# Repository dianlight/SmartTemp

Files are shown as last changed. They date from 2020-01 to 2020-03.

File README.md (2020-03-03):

<!--
*** Thanks for checking out this README Template. If you have a suggestion that would
*** make this better, please fork the repo and create a pull request or simply open
*** an issue with the tag "enhancement".
*** Thanks again! Now go create something AMAZING! :D
***
***
***
*** To avoid retyping too much info. Do a search and replace for the following:
*** github_username, repo, twitter_handle, email
-->

<!-- PROJECT SHIELDS -->
<!--
*** I'm using markdown "reference style" links for readability.
*** Reference links are enclosed in brackets [ ] instead of parentheses ( ).
*** See the bottom of this document for the declaration of the reference variables
*** for contributors-url, forks-url, etc. This is an optional, concise syntax you may use.
*** https://www.markdownguide.org/basic-syntax/#reference-style-links
-->
[][contributors-url]
[][forks-url]
[][stars-url]
[][issues-url]
[][license-url]
[][linkedin-url]

<!-- PROJECT LOGO -->
<br />
<p align="center">
  <a href="https://github.com/dianlight/SmartTemp">
    <!--
    <img src="images/logo.png" alt="Logo" width="80" height="80">
    -->
  </a>

  <h3 align="center">Smart Temp</h3>

  <p align="center">
    An DIY Smart Thermostat
    <br />
    <!--
    <a href="https://github.com/dianlight/SmartTemp"><strong>Explore the docs »</strong></a>
    <br />
    <br />
    -->
    <a href="https://github.com/dianlight/SmartTemp/blob/master/CHANGELOG.md">Changelog</a>
    ·
    <a href="https://github.com/dianlight/SmartTemp/issues">SmartTemp Bug</a>
    ·
    <a href="https://github.com/dianlight/SmartTemp/issues">Request Feature</a>
  </p>
</p>

<!-- Donations -->

<a href="https://www.buymeacoffee.com/ypKZ2I0" target="_blank">Buy Me A Coffee</a>

<!-- TABLE OF CONTENTS -->
## Table of Contents

- [Table of Contents](#table-of-contents)
- [About The Project](#about-the-project)
  - [Built With](#built-with)
- [Getting Started](#getting-started)
  - [Hardware Prerequisites](#hardware-prerequisites)
  - [Circuit](#circuit)
  - [Environment Prerequisites](#environment-prerequisites)
  - [Installation](#installation)
- [Config.h options](#configh-options)
- [Features / Whishlist](#features--whishlist)
- [Roadmap](#roadmap)
- [User Manual](#user-manual)
  - [Encoder function](#encoder-function)
  - [Thermal confort mode (Advanced)](#thermal-confort-mode-advanced)
  - [PMV/PPD method](#pmvppd-method)
  - [Modes](#modes)
  - [In house / away selection](#in-house--away-selection)
- [Contributing](#contributing)
- [License](#license)
- [Contact](#contact)
- [Acknowledgements](#acknowledgements)

<!-- ABOUT THE PROJECT -->
## About The Project

<!-- [![Product Name Screen Shot][product-screenshot]](https://example.com) -->
Just another smart thermostat!

In a smart home, a smart thermostat cannot be missing. So why not build one at low cost and with all the features that interest me.

The project started using material left over from other projects and respecting the following requirements:

* Low cost
* Independence from Cloud services (privacy first!)
* Small size (must be contained in a US size box)
* Be smart but if necessary work without WiFi and / or external controller
* KISS. Being able to be used by my wife, daughter, son, mother, father, grandmother, grandfather -> the whole family!

### Built With

* [Platform IO](http://platformio.org)

<!-- GETTING STARTED -->
## Getting Started

To get a local copy up and running follow these simple steps.

### Hardware Prerequisites

For a detailed list of components refer to the documentation (BOM)

1. I2C Advance Extender based on ATMEGA8A-PU (See project [at8i2cgateway](https://github.com/dianlight/a8i2cGateway))
2. MCU ESP-01 or ESP-01S
3. Serial programmer
4. I2C Oled display
5. Rotary encoder
6. DHT22 sensor
7. Relay 
8. 5v power source ( I used an Hi-Link 220v to 5v but you can use alse batteries )
9. Wires and Connectors 

### Circuit

***!Work in progress!***

### Environment Prerequisites

1. Platform IO ( to compile and generate the firmware )
2. An HomeAssistant installation ( used as Smart Controller ) ___(Optional)___ 
3. An MQTT Borker ___(Optional)___
4. An WiFi capable device like SmartPhone.
5. An WiFi internet connection

### Installation
 
1. Burn the bootloader into the ATMEGA8 with Arduino IDE and the SPI/ASP programmer
2. Clone the SmartTemp
```sh
git clone https://github.com/dianlight/SmartTemp.git
```
3. Open the project with Platform IO
4. Configure the firmware 
```src/include/Config.h```
5. Build and flash your firmware

<!-- USAGE EXAMPLES -->
## Config.h options

***!Work in progress!***

<!-- FEATURES -->
## Features / Whishlist

- [x] Standalone Thermostat
  - [x] Current Room Temperature
  - [x] Current Room Humidity
  - [x] 3 levels of temperatures. (ECO, NORMAL and CONFORT)
  - [x] Week programming (15min resolution)
- [ ] Supported units
  - [x] Celsius mode
  - [ ] Fahrenheit mode ( [Wikipedia](https://en.wikipedia.org/wiki/Fahrenheit) )
- [x] Advanced Thermostat
  - [x] Away/In_house temp control
  - [x] Auto, Manual and Off mode
  - [ ] Thermal confort mode 
    - [ ] [PMV/PPD method](https://en.wikipedia.org/wiki/Thermal_comfort#PMV/PPD_method)
    - [ ] [Adaptive comfort model](https://en.wikipedia.org/wiki/Thermal_comfort#Adaptive_comfort_model)<sup>1</sup>
    - [ ] [ASHRAE-55](https://comfort.cbe.berkeley.edu/)<sup>2</sup>
    - [ ] [EN-16798](https://comfort.cbe.berkeley.edu/)<sup>2</sup>
- [x] Smart Thermostat (Wifi remote controlled)
  - [x] MQTT transport
  - [x] HomeAssistant climate compatibility (via MQTT integration)
    - [ ] Homeassistant room presence integration ( auto AWAY/NORMAL mode )
  - [x] NTP clock sync (daylight auto switch)
    - [ ] Time Zone configuration
- [x] WebInterface
  - [ ] Mobile WebApp
- [ ] External sensor
  - [ ] Wifi temperature sensor
  - [ ] Wifi pressure sensor
  - [ ] Wifi air speed sensor
  - [ ] Home Assistant collector
- [x] Enclosure (3D STL printable models)
  - [x] Italian BTicino Living 2Gang
  - [ ] EU standard
  - [ ] UK standard
  - [ ] US standard

_*Checked are implemented_

_<sup>1</sup>Require external temperature sensor_

_<sup>2</sup>Require external temperature, pressure sensor and internet connection_

<!-- ROADMAP -->
## Roadmap

See the [open issues](https://github.com/dianlight/SmartTemp/issues) for a list of proposed features (and known issues).

<!-- USER MANUAL -->
## User Manual

### Encoder function

***!Work in progress!***

### Thermal confort mode (Advanced)

***!Work in progress not yet implemented!*** 

The thermal confort mode allows you to set the thermostat not based on the real  desired temperature but on the basis of the [confort temperature](https://en.wikipedia.org/wiki/Thermal_comfort#Interplay_of_temperature_and_humidity). This significantly increases comfort by reducing consumption.

### [PMV/PPD method](https://en.wikipedia.org/wiki/Thermal_comfort#PMV/)

![Temp/Humidity](https://upload.wikimedia.org/wikipedia/commons/thumb/a/a0/Temperature-relative_humidity_chart_-_PMV_method.png/1024px-Temperature-relative_humidity_chart_-_PMV_metho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)

### Modes 

| Mode | Description | Home modfity | Away modify | Note |
| --- | --- | --- | --- | --- |
| Auto | Follow the Week program to set *Eco*, *Normal* or *Confort* target temp | none | &plusmn; delta | |
| Manual | Follow the setting of selected target temp | none | &plusmn; delta | return to *Auto* mode after impoisted time |

### In house / away selection

| Selection | Mode | Description | Function | Note |
| --- | --- | --- | --- | --- |
| In house  | Auto | Standard mode | Follow week program | |
| In house  | Manual | Temporary mode | Follow selected target temperature until timeout expire | Automatic return to *Auto* mode |
| Away      | Auto | Advanced mode | Follow week program with a &plusmn; temperature delta | |
| Away      | Eco  | Advanced mode | Lock to *Eco* target temperature  with a &plusmn;  delta | No automatic return to *Auto* mode |
| Away      | Normal  | Advanced mode | Lock to *Normal* target temperature with a &plusmn;  delta | No automatic return to *Auto* mode |
| Away      | Confort  | Advanced mode | Lock to *Confort* target temperature with a &plusmn;  delta | No automatic return to *Auto* mode |

<!-- CONTRIBUTING -->
## Contributing

Contributions are what make the open source community such an amazing place to be learn, inspire, and create. Any contributions you make are **greatly appreciated**.

1. Fork the Project
2. Create your Feature Branch (`git checkout -b feature/AmazingFeature`)
3. Commit your Changes (`git commit -m 'Add some AmazingFeature'`)
4. Push to the Branch (`git push origin feature/AmazingFeature`)
5. Open a Pull Request

<!-- LICENSE -->
## License

Distributed under the GPL3 License. See `LICENSE` for more information.

<!-- CONTACT -->
## Contact

<!--
Your Name - [@twitter_handle](https://twitter.com/twitter_handle) - email
-->

Project Link: [https://github.com/dianlight/SmartTemp](https://github.com/dianlight/SmartTemp)

<!-- ACKNOWLEDGEMENTS -->
## Acknowledgements

Icons made by <a href="https://www.flaticon.com/authors/pixel-perfect" title="Pixel perfect">Pixel perfect</a> from <a href="https://www.flaticon.com/" title="Flaticon"> www.flaticon.com</a>

<!--
* [RobTillaart](https://github.com/RobTillaart/) for the Arduino libraries
* [soligen2010](https://github.com/soligen2010/) for the ClickEncoder fork
  -->

<!-- MARKDOWN LINKS & IMAGES -->
<!-- https://www.markdownguide.org/basic-syntax/#reference-style-links -->
[contributors-shield]: https://img.shields.io/github/contributors/dianlight/SmartTemp.svg?style=flat-square
[contributors-url]: https://github.com/dianlight/SmartTemp/graphs/contributors
[forks-shield]: https://img.shields.io/github/forks/dianlight/SmartTemp.svg?style=flat-square
[forks-url]: https://github.com/dianlight/SmartTemp/network/members
[stars-shield]: https://img.shields.io/github/stars/dianlight/SmartTemp.svg?style=flat-square
[stars-url]: https://github.com/dianlight/SmartTemp/stargazers
[issues-shield]: https://img.shields.io/github/issues/dianlight/SmartTemp.svg?style=flat-square
[issues-url]: https://github.com/dianlight/SmartTemp/issues
[license-shield]: https://img.shields.io/github/license/dianlight/SmartTemp.svg?style=flat-square
[license-url]: https://github.com/dianlight/SmartTemp/blob/master/LICENSE
[linkedin-shield]: https://img.shields.io/badge/-LinkedIn-black.svg?style=flat-square&logo=linkedin&colorB=555
[linkedin-url]: https://www.linkedin.com/in/lucio-tarantino-8ab9a3/
[product-screenshot]: images/screenshot.png
[buy-me-a-coffe]: https://www.buymeacoffee.com/ypKZ2I0

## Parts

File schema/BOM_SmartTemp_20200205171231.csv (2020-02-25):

ID | Name | Designator | Footprint | Quantity | Manufacturer Part | Manufacturer | Supplier | Supplier Part | LCSC Assembly
1 | 10K | R1 | R10K | 1
2 | 3PIN | J1 | 3PIN | 1
3 | 16MHz | X1 | HC-49US_L11.5-W4.5-P4.88 | 1 | XIHCELNANF-8MHZ | TAITIEN Elec | LCSC | C295088
4 | AC220VPIN | U10 | AC220PIN | 1 | AC220VPIN
5 | ESP Program | U3 | 2 PIN | 1 | Precision potentiometer100Ω
6 | ESP Serial | U8 | 2 PIN | 1 | Precision potentiometer100Ω
7 | A8 Serial | U9 | 2 PIN | 1 | Precision potentiometer100Ω
8 | 330 | R6,R7 | PKG-0.25W RESISTOR | 2 | MCF 0.25W 120R | MULTICOMP | Element14 | 9339116
9 | ROTARY_ENCODER_LABELED | U7 | 5 PIN | 1 | ROTARY_ENCODER | STMicroelectronics |  | C157406 | Yes
10 | DHT22 | U4 | 4PIN | 1
11 | A8 Reset/Program | SW1 | SW-TH_4PIN-L6.00-W6.00 | 1 | Switch,6*6*6Plastic head,260G, 0.25mm,Straight line | BBJ | LCSC | C71836
12 | ESP Reset | SW2 | SW-TH_4PIN-L6.00-W6.00 | 1 | Switch,6*6*6Plastic head,260G, 0.25mm,Straight line | BBJ | LCSC | C71836
13 | 3K3 | R2,R5 | AXIAL10 | 2 | Resistor MF25 3K3, 0.25W |  | Element14 | 934-1749
14 | 22pF | C1,C2 | CERAMIC-2.54 | 2 | CS1-D5Y5V2A104ZSP |  | SeeedStudio | 302010200
15 | HILINK | U1 | HI-LINKAC-5VDC | 1
16 | SSH1106_1.3in_128x64_I2C_OLED_NEW | DISP1 | I2C CONNECTOR | 1 | Tribium
17 | ATMEGA8A-PU | U2 | DIP-28_L34.6-W7.3-P2.54-LS10.2-BL | 1 | ATMEGA8A-PU | MICROCHIP | LCSC | C34931
18 | ARDUINO KY-019W 5V | U6 | ARDUINO RELAY KY-019 5V | 1 | SRD-05VDC-SL-C |  | eBay | undefined
19 | AMS117，SOT223 COPY | U5 | 3 PIN | 1
20 | 0.1uF | CC1,CC2 | CAP_CER | 2
21 | ESP-01S_C82893 | MK1 | WIRELM-TH_ESP-01S | 1 | ESP-01S | Ai-Thinker | LCSC | C82893

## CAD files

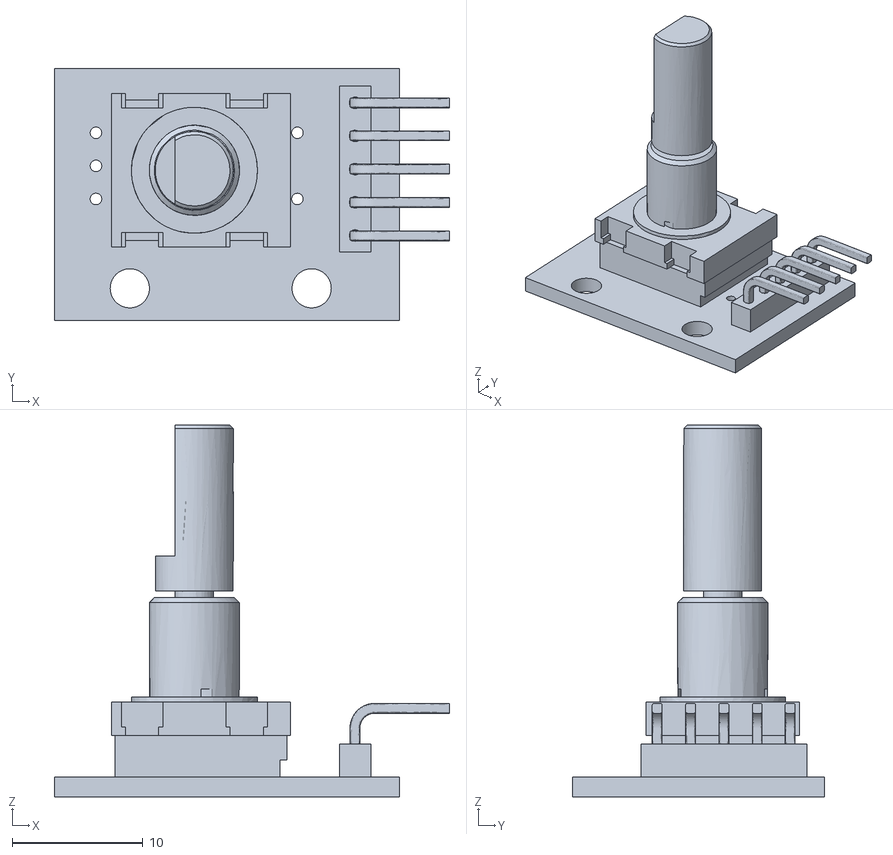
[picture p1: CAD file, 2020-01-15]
case/Rotary_Encorder_KY-040.stl
30.2 x 19.3 x 28.5

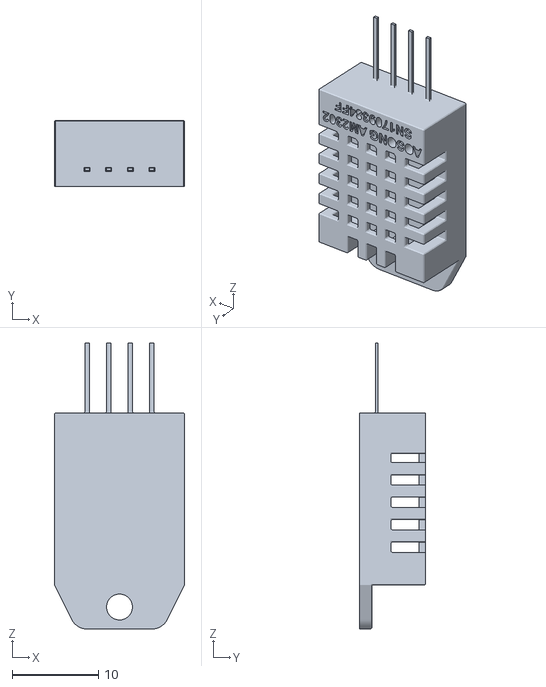
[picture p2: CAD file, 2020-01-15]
case/DHT22.stl
15.1 x 7.70 x 33.2

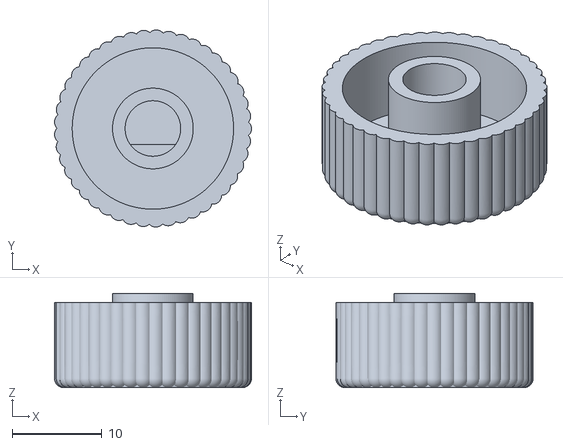
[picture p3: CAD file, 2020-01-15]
case/Rotary_Encoder_Knob.stl
22.0 x 22.0 x 10.5

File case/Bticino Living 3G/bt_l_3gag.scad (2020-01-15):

//use<threads.scad>
//use <096Oled.scad>;
include <NopSCADlib/lib.scad>
use <threadlib/threadlib.scad>
use <OLED_13_128_64.scad>

include <096OledDim.scad>;


renderNop = false;
nutmount = true;

$fn=60;

union(){

    difference(){
        translate([0,0,-0.8])extBox([43.3,66.0,58.8]);
        translate([0.1,0,1])extBox([41.0,63,58.8]);
        translate([39.5,0,19]) cube([4,66.0,48.8]);
        translate([39.5,0,19]) rounded_rectangle([4,66.0,48.8],r=1,center=false);
        translate([1.2,2.0,18.8]) cube([43.0,62.0,40]);
        translate([20,67,33]) rotate([90,90,0]) tearslot(68.2, 10,20, center = false, truncate = true);
  
        
        // OLED
        rotate([0,180,0]){
            translate([-23.5,19.9,-4]) {
              rounded_rectangle([18.8,31.8,5],r=1,center=false);
            }
        }
 //       rotate([180,0,90])
 //         translate([20,25,-2]) {
 //           OLED_13_128_64_I2C(1,0);  
 //           DisplayLocalize(type=I2CSPI7, align=2, dalign=1)
 //               translate([0,0,6.0/2])
 //                   cube([CRIUS_LVW,CRIUS_LVL,6.0], center=true);
 //         }
        // Enc
        rotate([180,0,180])  
          translate([-28.05, 55,-2])
            cylinder(h=5,r=3.8);
          
          
/*        
       translate([22,10,0.5])
          rotate([0,0,-90])
          scale([0.1, 0.1, 0.1])
         surface(file = "lamp.png", center = true, invert = true);
        
       translate([22,32,0.5])
          rotate([0,0,-90])
          scale([0.1, 0.1, 0.1])
         surface(file = "lamp2.png", center = true, invert = true);

       translate([22,55,0.5])
          rotate([0,0,-90])
          scale([0.1, 0.1, 0.1])
         surface(file = "lamp2.png", center = true, invert = true);
 */  
       
        
        // Buco bottone Reset
        translate([2,18,-2])cylinder(r=1,h=28,$fn=60);
        translate([2,11,-2])cylinder(r=1,h=28,$fn=60);
        //translate([39,17,0]) linear_extrude(height=2)  rotate([180,0,90]) text("Connesso", font = "Liberation Sans",  size = 1.3);
        // Buco DHT22
        translate([12,50.9,-2]) rounded_rectangle([16,21,5],r=0.5,center=false);
        translate([6,61+2,1.7]) cube([12,5,2]);
        // Buco fissaggio OLED
        translate([4,-2,2]) cube([35,5,2]);
        

 
    }
//        translate([3.5,40.5,-2]) cube([16,22,5]);

     rotate([0,180,0])
      translate([-40,3,-3])  {
        translate([33,32,0]) m2hold();  
        translate([33,32-30,0]) m2hold();  
        translate([32-27,32-30,0]) m2hold();  
        translate([32-27,32,0]) m2hold();  
//        translate([32-27,32,0]) nut("M2",turns=5,Douter=4.2);  
      }

    if(nutmount){
         translate([33.2,46,0.5]){
            nut("M2",turns=26,Douter=6); 
            translate([-7,0,4.7]) cube([12,4,12],center=true);
            translate([5.5,0,4.7]) cube([9,4,12],center=true);
         }
     }
      
    if(renderNop){
        rotate([0,180,0])
          translate([-39,3,-4]) {
 //           DisplayModule(type=I2CSPI7, align=2, G_COLORS=true); 
            OLED_13_128_64_I2C(1,0);  
   
          }
        rotate([180,0,180])  
          translate([-163,207,-14])
            import("../Rotary_Encorder_KY-040.stl");   
          
        translate([19,61,3.5]) rotate([90,180,0]) import("../DHT22.stl");
         
        translate([27,55,-15]) import("../Rotary_Encoder_knob.stl"); 
    }
    
    PERF60x40_1 = ["PERF60x40", "Perfboard 60 x 40mm"
       , 60
       , 40
       , 1.6
       , 0
       , 2.3
       , 0
       , "green"
       , true
       , 
       [ 
         [1.9,1.9],
         [-1.9,1.9],
         [1.9,-1.9],
         [-1.9,-1.9]
       ], [], [], [5.87, 3.49]];
       
      rotate([90,0,90]) translate([33,37,10]){
          if(renderNop)pcb(PERF60x40_1);
          pcb_screw_positions(PERF60x40_1){
            translate([0,0,-9.5]){
               if(nutmount) nut("M2",turns=20,Douter=6); 
            } 
          }
      }

    
    
    
    // Supporti Scheda
 //   translate([3+1.9,   7,2]) threadSupport();
 //   translate([3+1.9,   53+7,2]) threadSupport();
 //   translate([38+0.6,  53+7,2]) threadSupport();
 //   translate([38+0.6,  7,2]) threadSupport();
 //   %translate([2,3,10]) cube([40,60.2,1.5]);
 
    // Ganci Living
   translate([0,16.9,18.8-8.6])  rotate([90,0,270]) hookMount();

   translate([43.3,16.9-11.5,18.8-8.6])  rotate([90,0,-270]) hookMount();

   translate([0,16.9+21.7,18.8-8.6])  rotate([90,0,270]) hookMount();

   translate([43.3,16.9-11.5+21.7,18.8-8.6])  rotate([90,0,-270]) hookMount();

   translate([0,16.9+(21.7*2),18.8-8.6])  rotate([90,0,270]) hookMount();

   translate([43.3,16.9-11.5+(21.7*2),18.8-8.6])  rotate([90,0,-270]) hookMount();
    
    
}

module extBox(dim){
    translate([21.6,33,29.4]) rotate([90,90,0]) rounded_rectangle([dim.z,dim.x,dim.y],r=4,center=true);
//    intersection(){
//      cube(dim);
//       translate([43.5/2,66,58]) 
//            rotate([90,0,0]) 
//                cylinder(r1=60,r2=60,h=66,$fn=260);
//
//    }

}

module threadSupport(){
    difference () {
        cylinder (r=3, h=5, $fn=100);
     metric_thread (diameter=2, pitch=1, length=6, internal=true, n_starts=6);
    }
}


module hookMount(){
    union(){
        difference(){
            cube([11.8,8.6,3-1.2]);
            translate([(11.8-9.2)/2,1.9,0]) cube([9.2,8.4,3-1.2]);
            translate([3.3,0,0]) cube([4.9,8.6,3-1.2]);
        }
        CubePoints = [
          [  3.3,  5.4,  0 ],  // 0
          [  3.3+4.9,  5.4,  0 ],  // 1
          [  3.3+4.8,  8.6,  0 ],  // 2
          [  3.3, 8.5, 0 ], // 3
          [  3.3,  5.4,  3-1.2 ],  //4
          [  3.3+4.9,  5.4,  3-1.2 ], //5 
          [  3.3+4.9,  10.1,  3-1.2 ],  //6
          [  3.3,  10.1,  3-1.2 ],  //7
         ]; 
  
        CubeFaces = [
          [0,1,2,3],  // bottom
          [4,5,1,0],  // front
          [7,6,5,4],  // top
          [5,6,2,1],  // right
          [6,7,3,2],  // back
          [7,4,0,3]]; // left
          
        polyhedron( CubePoints, CubeFaces );
    }
    
    
}

module m2hold() {
    translate([0,0,-2.2]){
      difference(){ 
        union(){   
           cylinder(r1=1.5,r2=3.9/2,h=2);
           cylinder(r=1.5,h=6);
        }
        cube([4,0.8,7],center=true);
 //       cube([0.8,4,7],center=true);
      }
    }
}

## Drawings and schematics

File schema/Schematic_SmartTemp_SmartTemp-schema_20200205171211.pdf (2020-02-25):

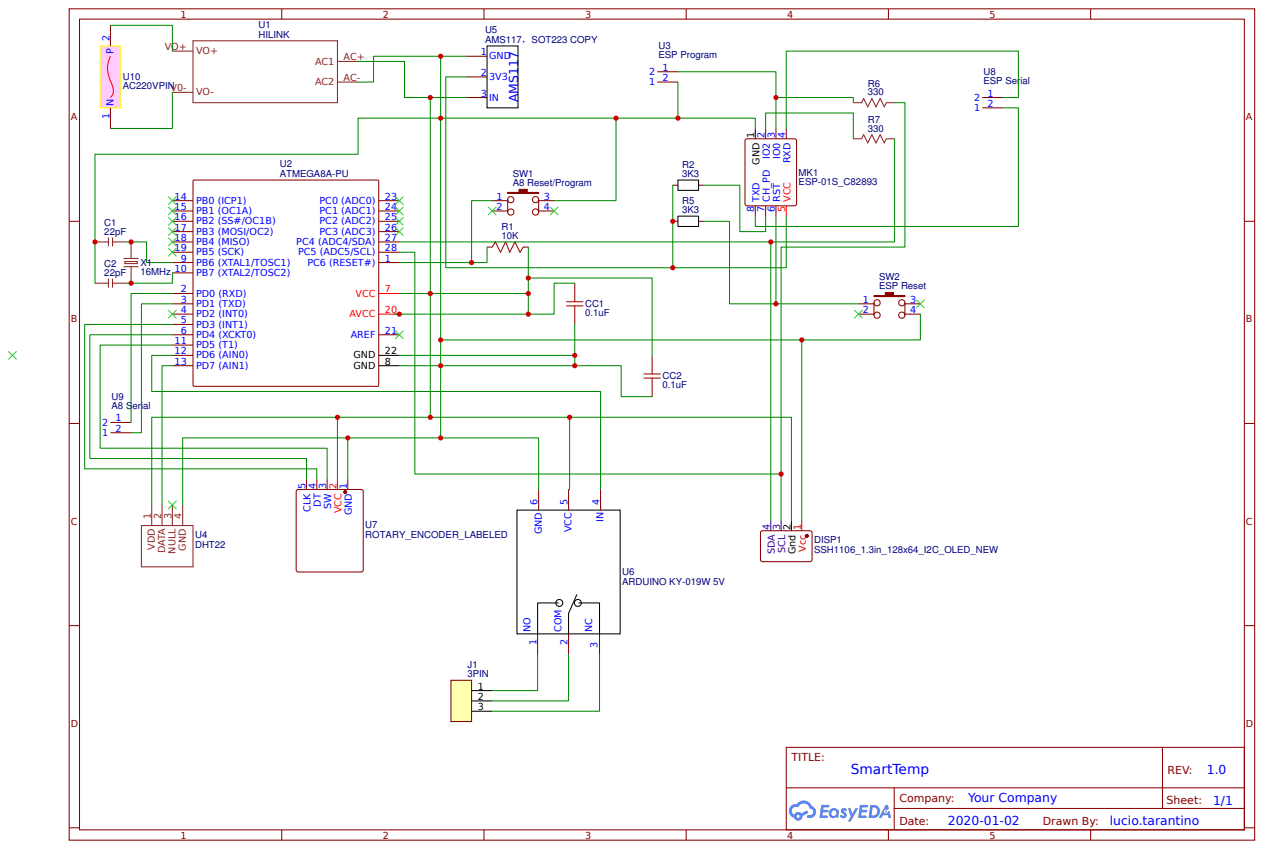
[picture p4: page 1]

RXD 4 VCC 5 RST 6 CH_PD 7 TXD 8

Vcc 1 Gnd 2 SCL 3 SDA 4

Drawn By: lucio.tarantino

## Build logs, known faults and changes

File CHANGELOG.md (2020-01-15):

# **Change Log** 📜📝

All notable changes to the "**SmartTemp**" WhatItIs/program/extension/API/whatever will be documented in this file.

The format is based on [Keep a Changelog](https://keepachangelog.com/en/1.0.0/) and this project adheres to [Semantic Versioning](https://semver.org/spec/v2.0.0.html).

---

# Changelog

## [Unreleased]

### Added

- Initial version.

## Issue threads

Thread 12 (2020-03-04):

Web UI responsive on small device.

dianlight, 2020-03-04:
Correct web ui on small device ( phones )

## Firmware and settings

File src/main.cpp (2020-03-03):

/*
 * SmartTemp
 * 
 * Smart Thermostat
 */
#include "EvoDebug.h"
#include <ESP8266mDNS.h>
#include <Wire.h>
#include <ArduinoOTA.h>
#include <WiFiUdp.h>

#include "Config.h"
#include "EvoWifi.h"
#include "Display.h"
#include "OTA.h"
#include "at8i2cGateway.h"
#include "TimeNTPClient.h"
#include "I2CDebug.h"
#include "Thermostat.h"
#include "EvoWebserver.h"
#include "MQTTforHA.h"
             
WiFiEventHandler stationConnectedHandler,stationModeDisconnectedHandler;

void onStationModeGotIP(const WiFiEventStationModeGotIP& evt) {

  debugI("IP %s/%s gw %s",evt.ip.toString().c_str(),evt.mask.toString().c_str(),evt.gw.toString().c_str());

  display.bootConnectedDisplay();
  ota.addOtaCallback([](OTA::OTA_EVENT event){
    switch (event)
    {
    case OTA::OTA_EVENT::START/* constant-expression */:
      evoWebserver.stop();
      at8gw.stop();
      break;
    case OTA::OTA_EVENT::STOP/* constant-expression */:
    case OTA::OTA_EVENT::ERROR/* constant-expression */:
      at8gw.start();
      evoWebserver.start();
      break;
    }
  });
  ota.start();

  mQTTforHA.start();

  evoWebserver.start();
}

void onStationModeDisconnected(const WiFiEventStationModeDisconnected& evt ){
  debugI("Station Mode disconnected!");

  ota.stop();
  mQTTforHA.stop();
}

void setup()
{
  stationConnectedHandler = WiFi.onStationModeGotIP(&onStationModeGotIP);
  stationModeDisconnectedHandler = WiFi.onStationModeDisconnected(&onStationModeDisconnected);

  Wire.begin();

  Serial.begin(74880);

  #ifdef DEBUG_I2C_SCAN
    delay(500);
    scanI2C();
  #endif

  at8gw.start();
  delay(500);

  if(at8gw.getEncoderButton() == AT8I2CGATEWAY::CLICK_CODE::HELD){
    debugD("AP config portal requested!");
    evoWifi.doAPConnect();
  } else if(!evoWifi.doSTAConnect()){
      debugW("Unable to connet to WiFi. Start in AP mode");
      evoWifi.doAPConnect();
  }

  thermostat.setHeatingCallback([](bool isHeating){
    #ifdef DEBUG_EVENT
      debugD("Relay %s %f > %f",isHeating?"On":"Off",at8gw.getTemperature(),at8gw.getTemperature());
    #endif
    at8gw.setRelay(isHeating);
    if (WiFi.status() == WL_CONNECTED){
      if(mQTTforHA.isRunning() && mQTTforHA.sendMQTTState()){
         mQTTforHA.sendMQTTAvail(true);
      }
    } 
  });

}   

void loop(){
}

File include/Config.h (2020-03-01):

#pragma once
#include <Arduino.h>

#define STR2(x) #x
#define STR(x) STR2(x)
#ifndef SMT_VERSION
    #define _SMT_VERSION ""
#else
    #define _SMT_VERSION STR(SMT_VERSION)   
#endif

#ifndef SMT_HOST
    #define _SMT_HOST "SmartTemp"
#else
    #define _SMT_HOST  STR(SMT_HOST)
#endif

#ifdef EVODEBUG
//    #define DEBUG_I2C_SCAN
//    #define DEBUG_I2C_IN
//    #define DEBUG_I2C_OUT
//    #define DEBUG_DISPLAY
//    #define DEBUG_MQTT
    #define DEBUG_EVENT
//    #define DEBUG_WEBSERVER
#endif

#include <time.h>
#include <TZ.h>
#define MYTZ TZ_Europe_Rome

// Pin Definition. NodeMCU
// LCD
#define SDA         0
#define SCL         2
#define LCD_ADDRESS 0x27

// AT8GW
#define AT8_I2C_GW  0x08

// RUNNING PARAMETERS
#define FIXED_TEMP_CORRECTION -2.0


// General Config
#define CONFIG_VERSION  "027"

// 
#define CONFIG_TARGET_STR    myConfig.CONFIG_TARGET_NAME[myConfig.getMode()->position]


#include "Constants.h"


class Config {
    public:

        enum __attribute__((__packed__)) MODES {
            OFF,     
            MANUAL,  
            AUTO,

            M_SIZE    
        };
        enum __attribute__((__packed__)) HOLDS {
            ECO,     
            NORMAL,  
            CONFORT,

            H_SIZE    
        };
        enum __attribute__((__packed__)) AWAY_MODES {
            FIXED_ECO,     
            FIXED_NORMAL,  
            FIXED_CONFORT,
            AS_AUTO,

            AM_SIZE    
        };
        const char* MODES_NAME[3] = {"Off","Manual","Auto"};
        const char* MODES_MQTT_NAME[3] = {"off","heat","auto"};
        const char* HOLDS_NAME[3] = {"Eco","Normal","Confort"};
        const char* HOLDS_MQTT_NAME[3] = {"Eco","Normal","Confort"};
        const char* AWAY_MODES_NAME[4] = {"As Auto","To Eco","To Norm.","To Conf."};

        enum CONFIG_TARGET {
            ECO_TEMP = 0,
            NORMAL_TEMP,
            CONFORT_TEMP,
            MANUAL_TO_AUTO_TIME,
            AWAY_DIFF,
            AWAY_HOLDS,
            //  TIME_INTERNET,
            //  TIME_WEEKDAY,
            //  TIME_HOUR,
            //  TIME_MINUTE,
            WIFI,
            INFO,
            FACTORY_RESET,

            _CONFIG_MODE_SIZE
        };


        struct ConfigModeStruct {
            bool active = false;
            uint8_t position = ECO_TEMP;
            int8_t  encoder = 0;
            bool    doFactoryReset = false;
        };


        const char* CONFIG_TARGET_NAME[9] = {"Eco","Normal","Confort","Manual to Auto time","Away Delta","Away Holds","Info","WiFi","Factory Reset"};

        struct __attribute__((packed, aligned(1))) DayProgram {
            byte hourQuarterHolds[24*4] = {
                    ECO,     ECO,     ECO,     ECO,   // 0
                    ECO,     ECO,     ECO,     ECO,   // 1
                    ECO,     ECO,     ECO,     ECO,   // 2
                    ECO,     ECO,     ECO,     ECO,   // 3
                    ECO,     ECO,     ECO,     ECO,   // 4
                    ECO,     ECO,     ECO,     ECO,   // 5
                    ECO,  NORMAL,  NORMAL, CONFORT,   // 6
                CONFORT, CONFORT, CONFORT, CONFORT,   // 7
                CONFORT, CONFORT, CONFORT, CONFORT,   // 8
                CONFORT, CONFORT, CONFORT,  NORMAL,   // 9
                 NORMAL,  NORMAL,  NORMAL,  NORMAL,   // 10
                 NORMAL,  NORMAL,  NORMAL,  NORMAL,   // 11
                 NORMAL,  NORMAL,  NORMAL,  NORMAL,   // 12
                 NORMAL,  NORMAL,  NORMAL,  NORMAL,   // 13
                 NORMAL,  NORMAL,  NORMAL,  NORMAL,   // 14
                 NORMAL,  NORMAL,  NORMAL,  NORMAL,   // 15
                 NORMAL,  NORMAL,  NORMAL,  NORMAL,   // 16
                 NORMAL,  NORMAL,  NORMAL, CONFORT,   // 17
                CONFORT, CONFORT, CONFORT, CONFORT,   // 18
                CONFORT, CONFORT, CONFORT, CONFORT,   // 19
                CONFORT, CONFORT, CONFORT,  NORMAL,   // 20
                 NORMAL,  NORMAL,  NORMAL,     ECO,   // 21
                    ECO,     ECO,     ECO,     ECO,   // 22
                    ECO,     ECO,     ECO,     ECO,   // 23
                                            };
        };

        struct __attribute__((packed, aligned(1))) StoreStruct {
            char version[4]                 = CONFIG_VERSION;
            size_t configSize               = sizeof(StoreStruct);
            float targetTemp[HOLDS::H_SIZE] = {18.5,19.5,20.5};
            float awayModify                = -0.5;
            byte  awayMode                  = AWAY_MODES::AS_AUTO;
            float tempPrecision             = 0.2;
            uint8_t minSwitchTime           = 30;
            byte mode                       = MODES::AUTO;
            uint8_t returnAutoTimeout       = 30;
            bool away                       = false;
            byte hold                       = HOLDS::NORMAL;
            DayProgram weekProgram[7];
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

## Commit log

2020-01-15 Truncate history
    [DHT22.stl, Rotary_Encoder_Knob.stl, Rotary_Encorder_KY-040.stl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]
2020-01-15 Fix time comunication issue
    [main.cpp]
2020-01-15 versione definitiva case
    [bt_l_3gag.scad]
2020-01-15 - Display powersaving - Week Day Names - Config size check
2020-01-15 Code cleanup and use of fixed offset for temp.
    [Config.h, main.cpp]
2020-01-22 StoreStruct optimization Time posizion correction
    [Config.h, Display.cpp]
2020-01-22 Migrated to ArduinoJson 6.x
2020-01-24 Fix Bug #1 Webserver on port 80
    [Webserver.cpp, main.cpp]
2020-02-05 Circuits schema and BOM
    [BOM_SmartTemp_20200205171231.csv]
2020-02-26 Schema folder correction
    [BOM_SmartTemp_20200205171231.csv]

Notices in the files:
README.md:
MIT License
